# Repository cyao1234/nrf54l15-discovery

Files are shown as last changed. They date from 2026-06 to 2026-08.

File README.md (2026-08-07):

# nRF54L15 Discovery

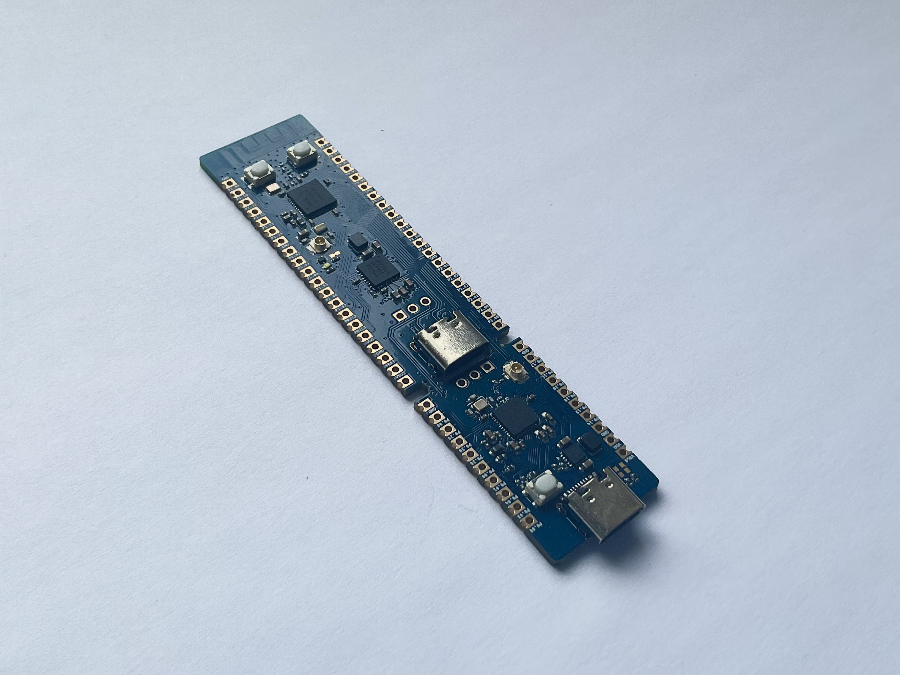
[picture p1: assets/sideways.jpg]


The nRF54L15 Discovery board is a development kit designed around the nRF54L15 and nRF52820 multiprotocol Bluetooth low-power SoCs. In the normal configuration, the nRF52820 is used as an interface CMSIS-DAP MCU, enabling onboard debugging and programming, eliminating the need for external debuggers. The Interface MCU interfaces with the host via USB and exposes an SWD and UART bridge for development usage.

Both MCUs are connected via two mousebite bridges, which can be snapped in two, allowing both chips to be used separately. Both boards have standalone voltage regulators and have their own USB-C power supply connector.

The processors are paired with an nPM1300 PMIC that supports LiPo charging and a TPS63900 high-efficiency, low Iq buck-boost converter. Both voltage regulators can be configured for 1.8V or 3.3V, enabling a flexible operating voltage domain. The nPM1300 also negotiates USB-C PD with your charger and dynamically changes the battery charging rate.

It also has USB-C, LEDs, Buttons, and U.FL receptacles for a 2.4 GHz Antenna and a 13.56 MHz NFC Antenna. The SWD and UART headers are exposed via I/O pins.

### Key Features
- Nordic Semiconductor [nRF54L15](https://www.nordicsemi.com/Products/nRF54L15) SoC
    - 128 MHz Arm Cortex®-M33 processor and 128 MHz RISC-V coprocessor 
    - 1.5 MB NVM and 256 KB RAM
    - Multiprotocol 2.4 GHz radio supporting Bluetooth Low Energy, 802.15.4-2020, and 2.4 GHz proprietary modes (up to 4 Mbps)
    - Advanced security features with physical protection
    - Global RTC (GRTC) available in System OFF mode
    - 5x SPI/UART/I2C, 3x PWM, 2x QDEC, I2S, PDM, 14-bit ADC, GPIOs
    - Integrated NFC-A Tag
    - 0.7 μA to 2.9 μA sleep mode power consumption
    - U.FL NFC connector
- Nordic Semiconductor [nRF52820](https://www.nordicsemi.com/Products/nRF52820) SoC
    - 64 MHz Arm Cortex®-M4
    - 256 KB Flash and 32 KB RAM
    - Full Speed USB 2.0
    - Bluetooth Low Energy multiprotocol
    - U.FL 2.4GHz NFC Antenna
- [nPM1300](https://www.nordicsemi.com/Products/nPM1300) 500 nA PMIC with integrated 32-800mA LiPo battery charger
    - 200 mA buck-boost converter with 93% efficiency
    - 50 mA switchable LDO for LEDs (turn off for 0 current leakage)
    - 1.0-3.3V variable voltage configurable in 100 mV steps
    - 32-800 mA LiPo battery charger with power path
    - USB Type-C compliant with 100 mA, 500 mA, and 1500 mA current limit
- Up to 48 GPIOs (29 for nRF54L15, 15 for nRF52820, 2 for nPM1300)
- Shipped with CMSIS-DAP pre-flashed on the nRF52820, ready for direct use
- ARM Serial Wire Debug (SWD) port via edge pins and 3-pin header
- TPS63900 75 nA buck-boost converter with 1.8V/3.3V configurable power supply for I/Os
- USB-C, user LED and buttons
- Dual-row 40+20 pins in 91x21mm form factor with castellated edges
- Snappable into 2 individual devboards, all capable of standalone operations
- Supports Zephyr, nRF Connect SDK, Python, etc.



### Hardware Diagram

The hardware design files are also available on [GitHub](https://github.com/cheyao/nrf54l15-discovery/), licensed under the CERN OHL V2.

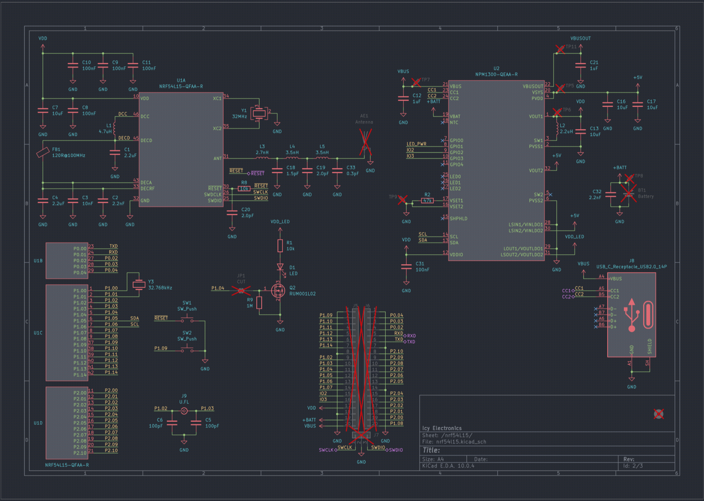
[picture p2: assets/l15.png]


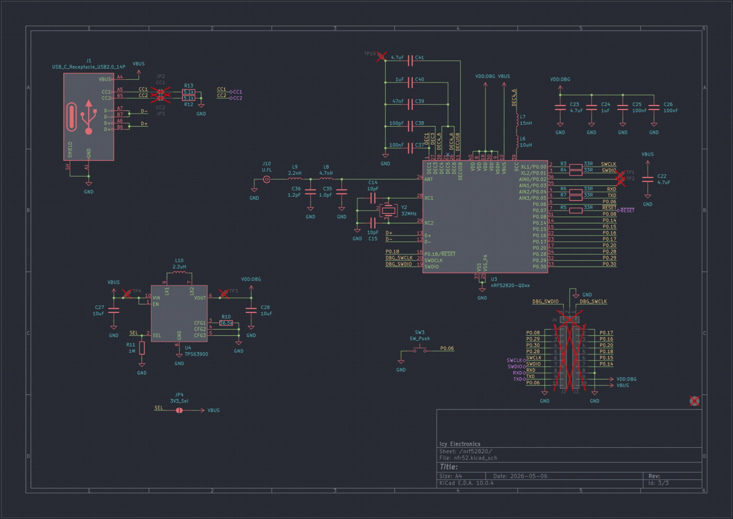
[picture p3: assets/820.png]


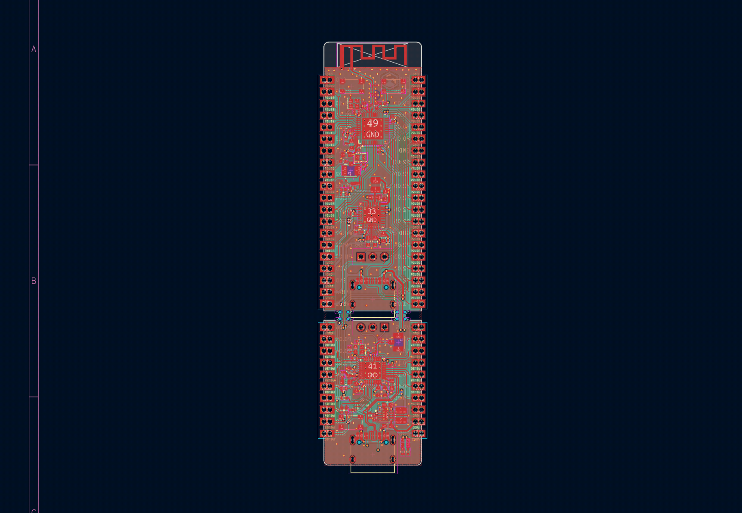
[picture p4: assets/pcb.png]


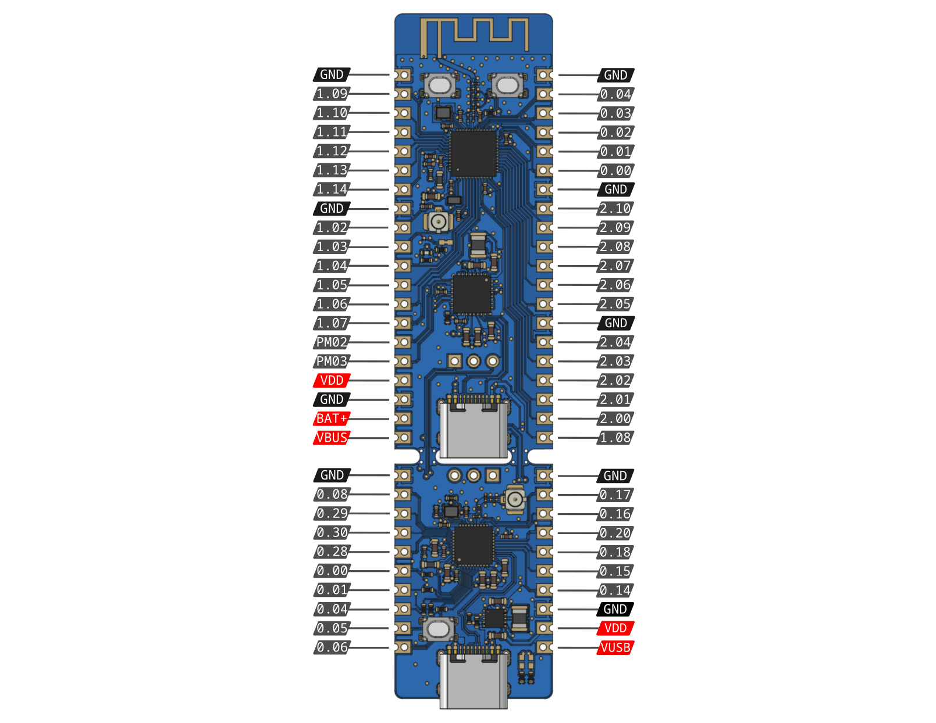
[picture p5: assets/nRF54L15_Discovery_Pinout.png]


### Programming guide

The board is programmable out of the box. Just run `west flash -r pyocd` to flash the board.

To get started, just follow Zephyr's [Getting Started](https://docs.zephyrproject.org/latest/develop/getting_started/index.html) guide. Everything is the same, except replace `<your-board-name>` with `nrf54l15_discovery/nrf54l15/cpuapp/s` (or without the `/ns` for secure version).

### Where to Buy

The nRF54L15 Discovery is available on the following sites:



(Got some extra units; cost covers material costs)

| Item | Price |
| --- | ---- |
| PCB | $120 |
| PCBA | $230 |

Download firmware here:
https://github.com/cheyao/nrf54l15-discovery/releases/tag/v1.0

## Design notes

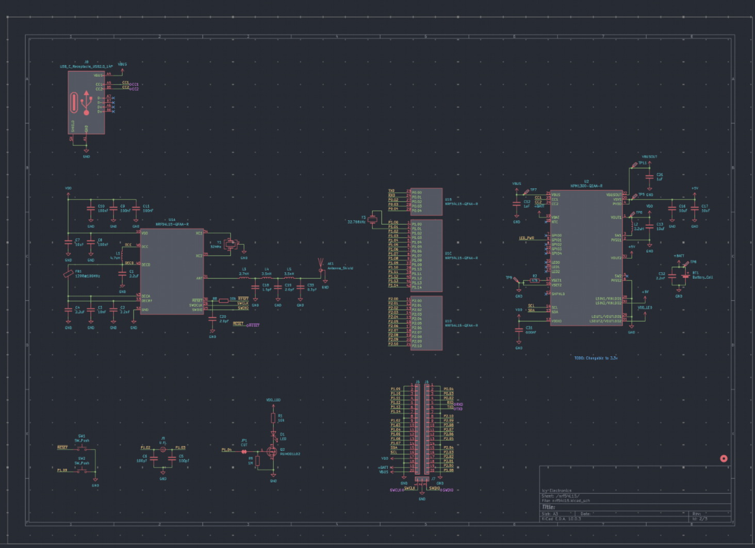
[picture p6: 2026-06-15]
assets/schematic-1.png

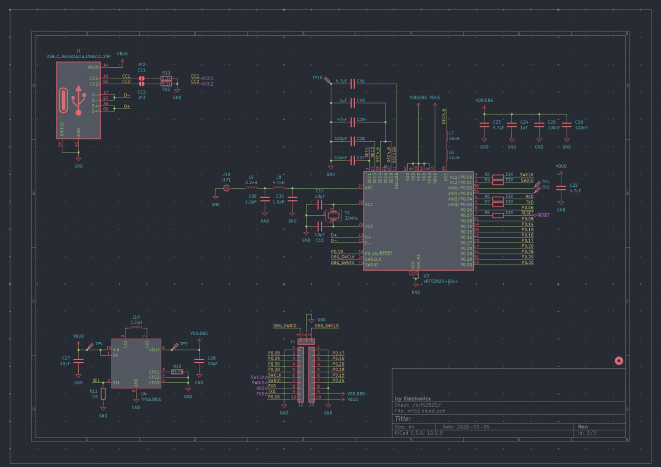
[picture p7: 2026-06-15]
assets/schematic-2.png

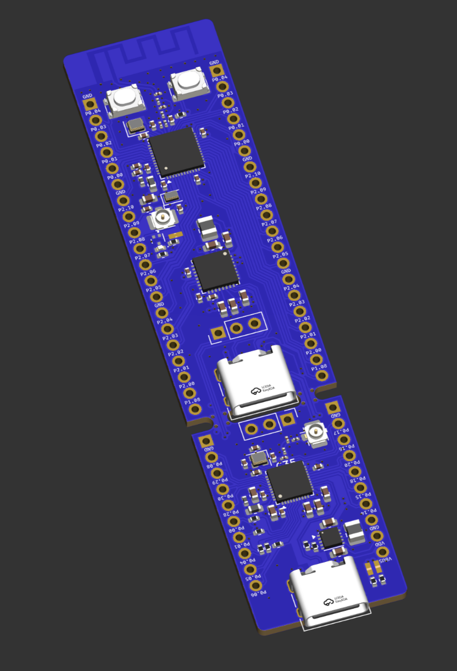
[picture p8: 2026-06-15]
assets/3d.png

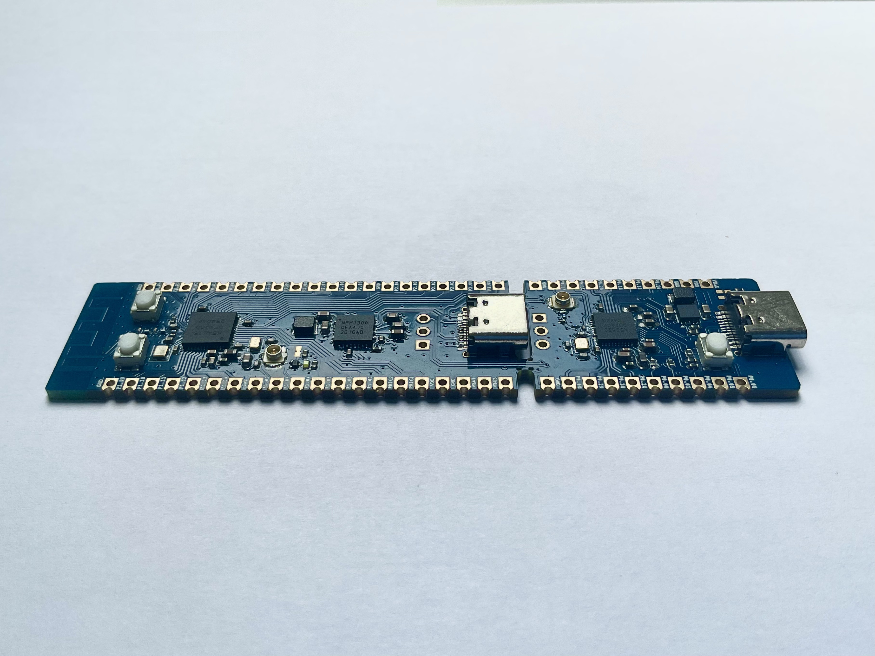
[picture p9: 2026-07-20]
assets/side.jpg

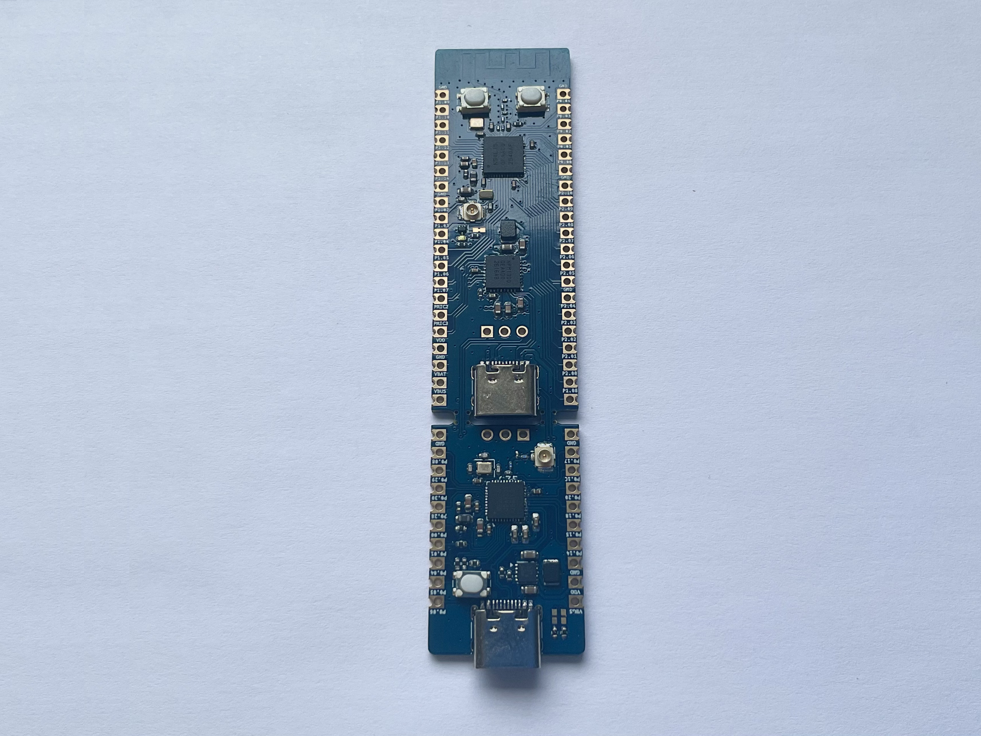
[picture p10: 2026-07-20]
assets/top-tilt.jpg

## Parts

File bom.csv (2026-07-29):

Item | Price
PCB | $120
PCBA | $230

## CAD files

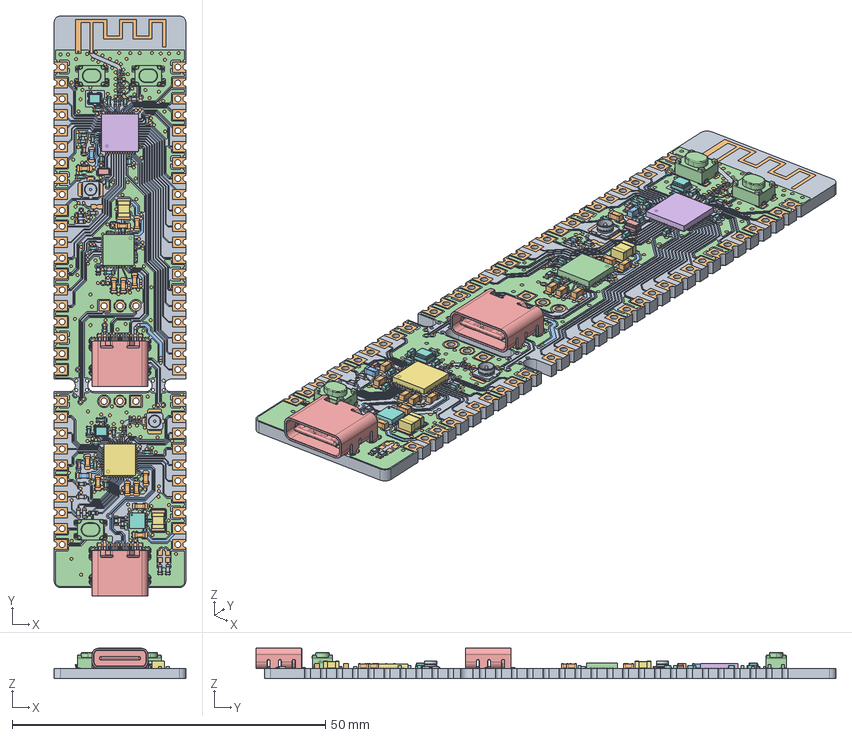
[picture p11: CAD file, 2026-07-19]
3d/nrf54.FCStd
21.0 x 92.5 x 4.87 mm
Pcb_dc15
topPads_dc15_cut
topTracks_dc15
topZones_dc15
botPads_dc15_cut
botTracks_dc15
botZones_dc15
C4_C_0402_1005Metric_efb7edfbfd87 x 20
R9_R_0402_1005Metric_148c62ffb333 x 13
L5_L_0201_0603Metric_c4573e2ac0c8 x 5
L1_L_0603_1608Metric_76ec2d2837d6 x 2
SW3_SW-SMD_4P-L4.2-W3.3-H2.5-P2.15-LS4.6_45902ee3bc6a x 3
USB-C_SMD-TYPE-C-31-M-12 x 2
U1_QFN_40_1EP_6x6mm_P05mm_bd9eb4529c85
L10_L_1008_2520Metric_1d597aab689b x 2
Y2_Crystal_SMD_2016-4Pin_2.0x1.6mm_cf03c7da0a9a x 2
J10_U.FL_Hirose_U.FL-R-SMT-1_Vertical_466a81a68c22 x 2
C21_C_0603_1608Metric_c42bb9afa9cc x 13
D1_LED_0402_1005Metric_9d2b405d5a38
U2_QFN_32_1EP_5x5mm_P05mm_EP33x33mm_112c5a95d446
FB1_L_0402_1005Metric_704f29023113 x 2
C36_C_0201_0603Metric_72dd63ce93f5 x 5
U3_QFN-40-1EP_5x5mm_Pitch0.4mm_b75e0b20a972
7a0a9878-926b-11ed-8620-a0cec80452fd_part
7a0a9b48-926b-11ed-8620-a0cec80452fd_part
7a0a9b48-926b-11ed-8620-a0cec80452fd_part001
7a0a9b48-926b-11ed-8620-a0cec80452fd_part002
7a0a9b48-926b-11ed-8620-a0cec80452fd_part003
7a0a9b48-926b-11ed-8620-a0cec80452fd_part004
7a0a9b48-926b-11ed-8620-a0cec80452fd_part005
7a0a9b48-926b-11ed-8620-a0cec80452fd_part006
7a0a9b48-926b-11ed-8620-a0cec80452fd_part007
7a0a9b48-926b-11ed-8620-a0cec80452fd_part008
7a0a9b48-926b-11ed-8620-a0cec80452fd_part009
7a0a9b48-926b-11ed-8620-a0cec80452fd_part010
7a0a9db4-926b-11ed-8620-a0cec80452fd_part

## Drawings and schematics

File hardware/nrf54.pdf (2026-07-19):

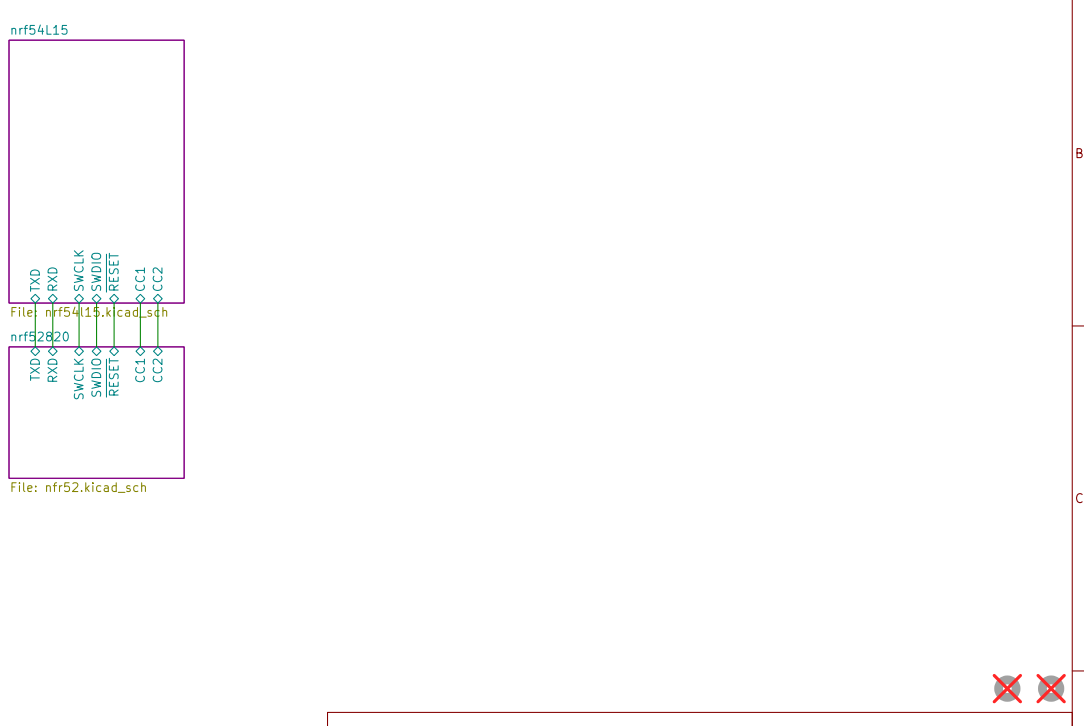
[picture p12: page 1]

Size: A4 | Rev: v1.0
KiCad E.D.A. 10.0.4 | Id: 1/3

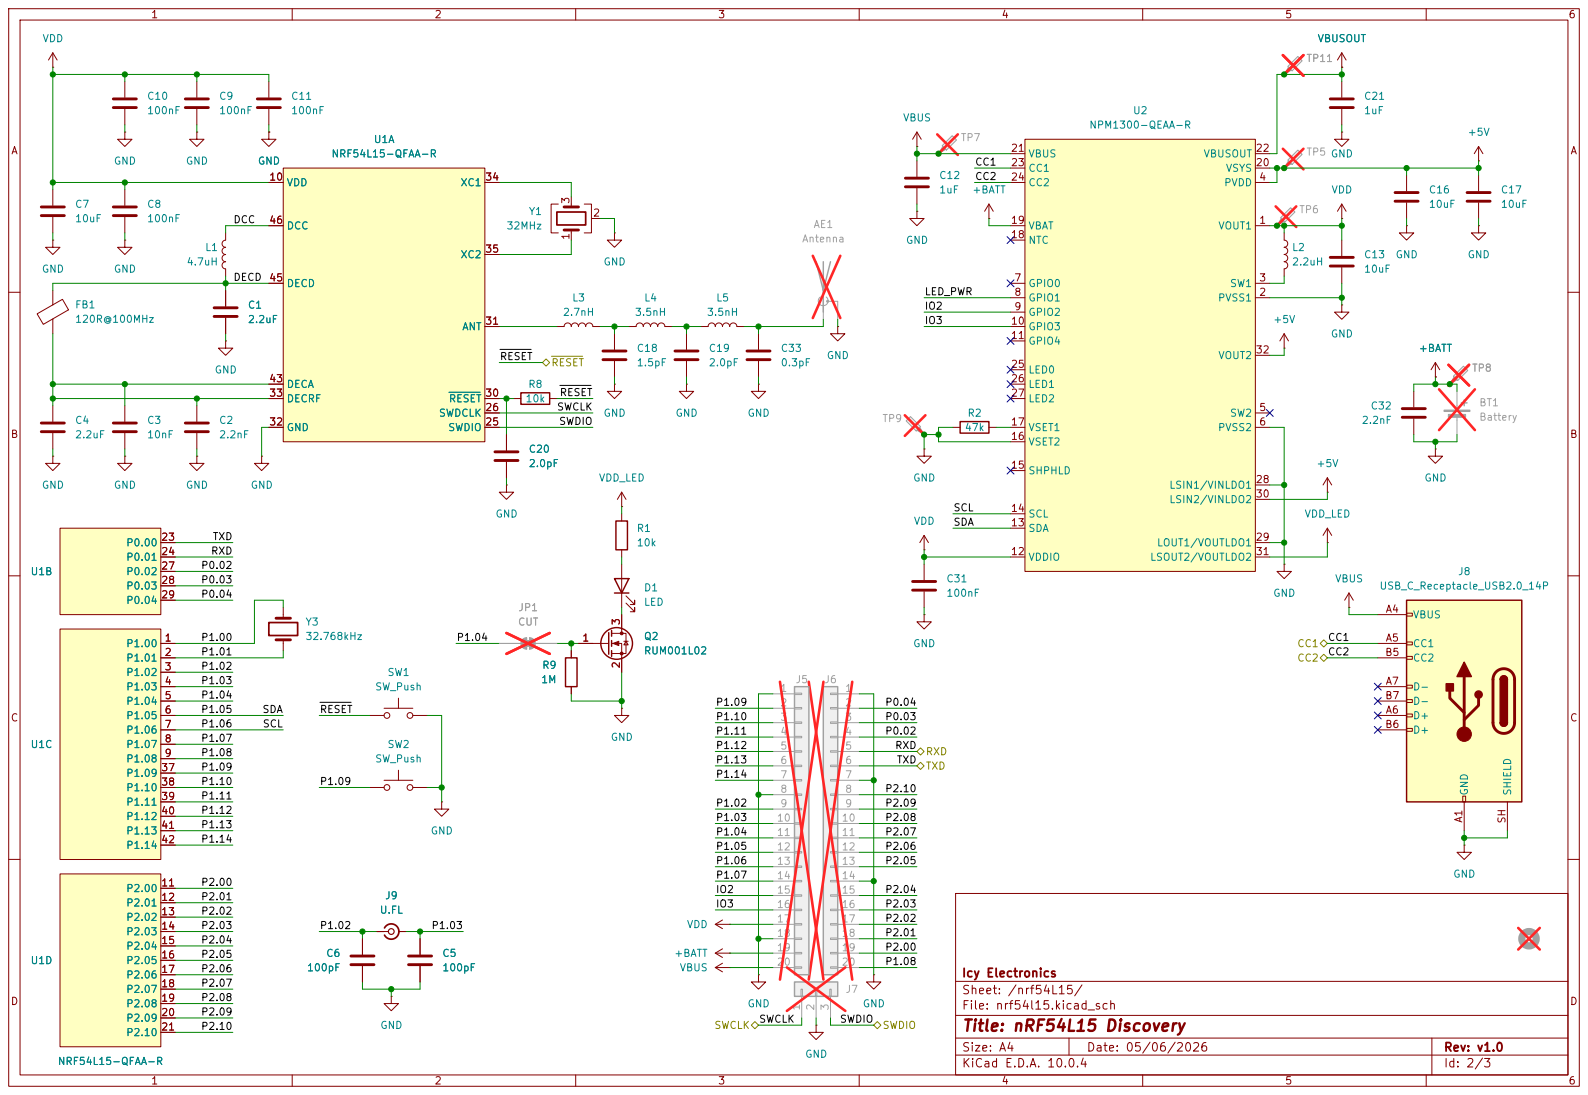
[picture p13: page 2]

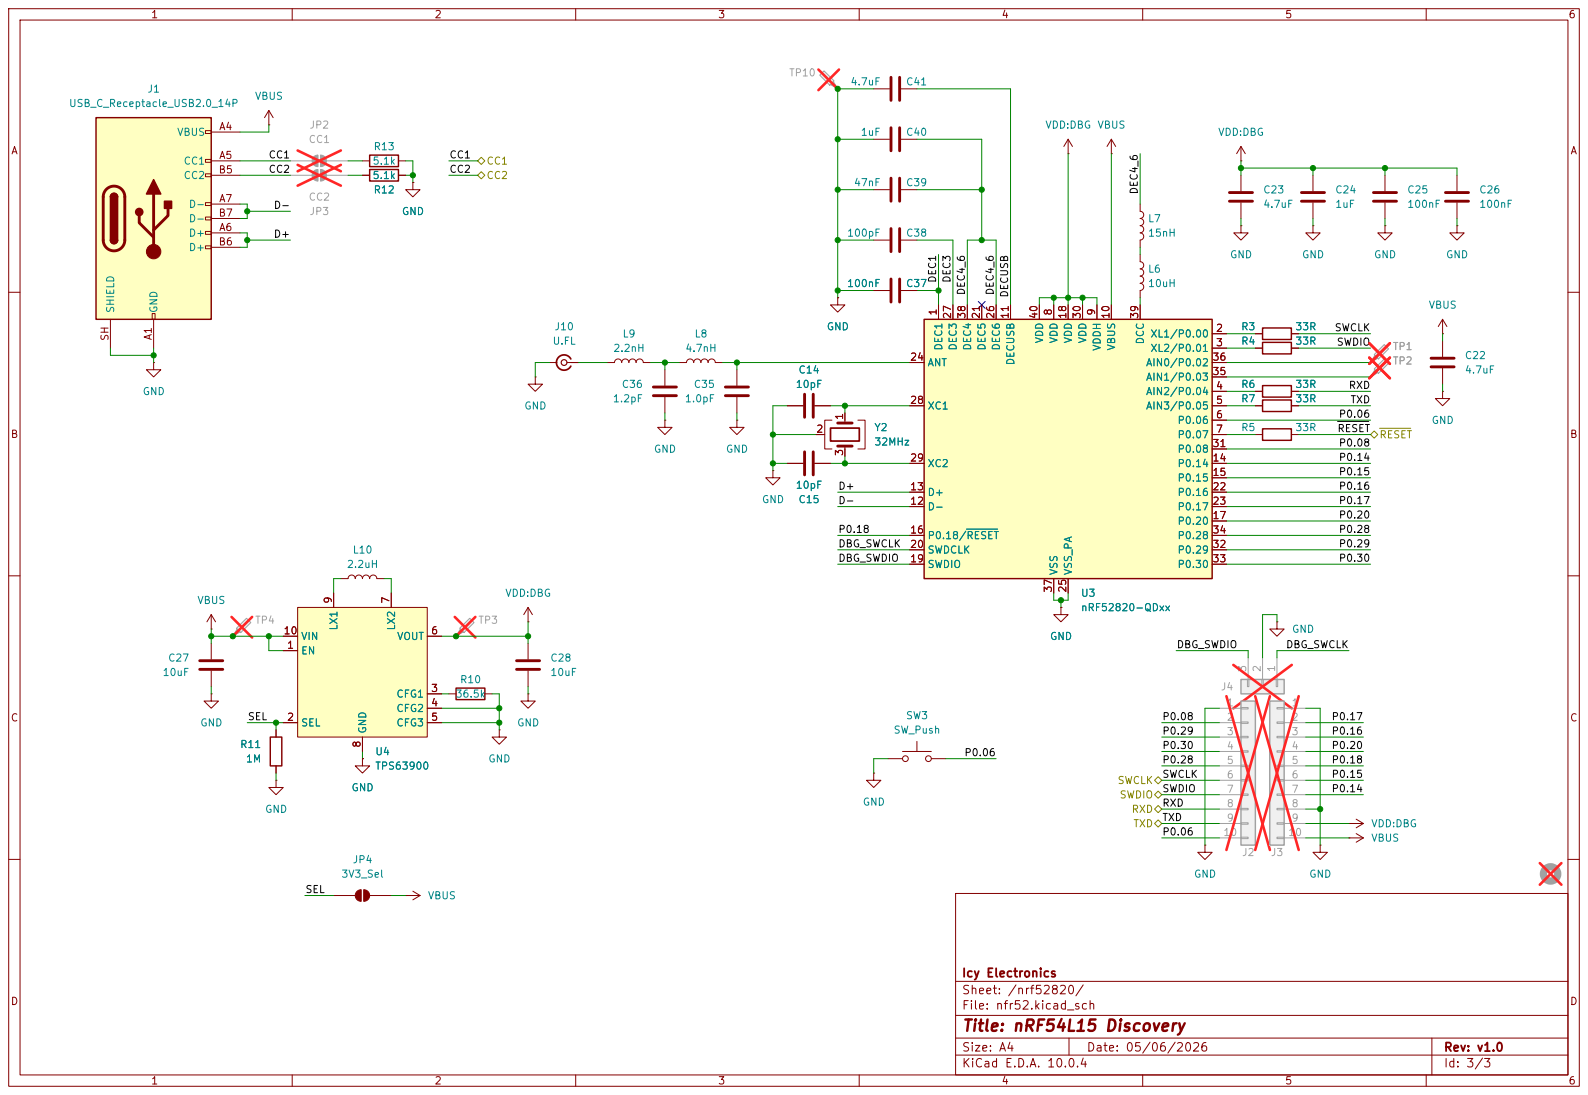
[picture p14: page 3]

9 VBUS 10 DECUSB 11 D- 12 D+ 13 P0.14 14 P0.15 15 P0.18/RESET 16 P0.20 17 VDD 18
nRF52820-QDxx DEC1

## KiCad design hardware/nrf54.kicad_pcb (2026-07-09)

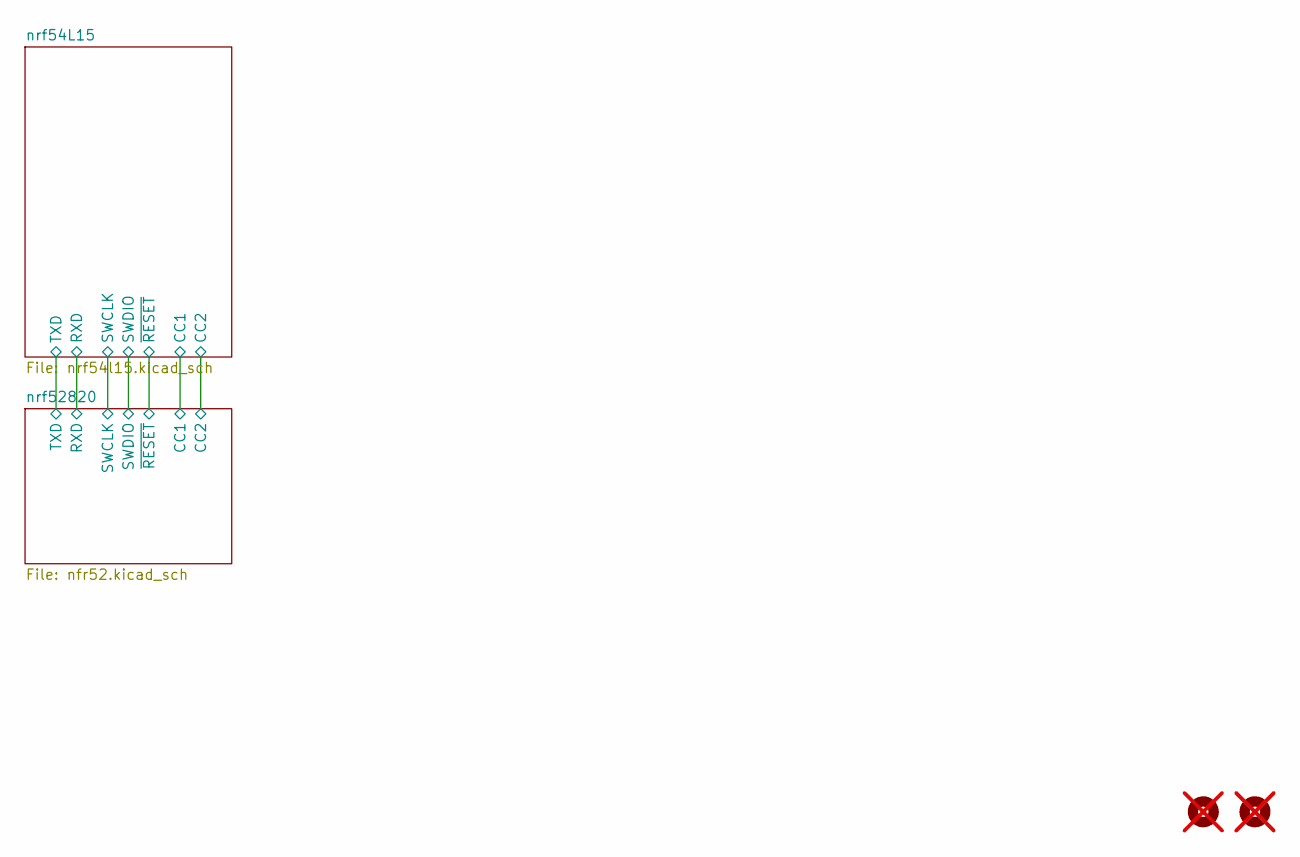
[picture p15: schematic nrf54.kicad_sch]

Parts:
H3, H4: MountingHole; MouseBite-Slot_2.0x2.0mm_outset_D0.5mm_P0.85mm_2h_Trace; not fitted

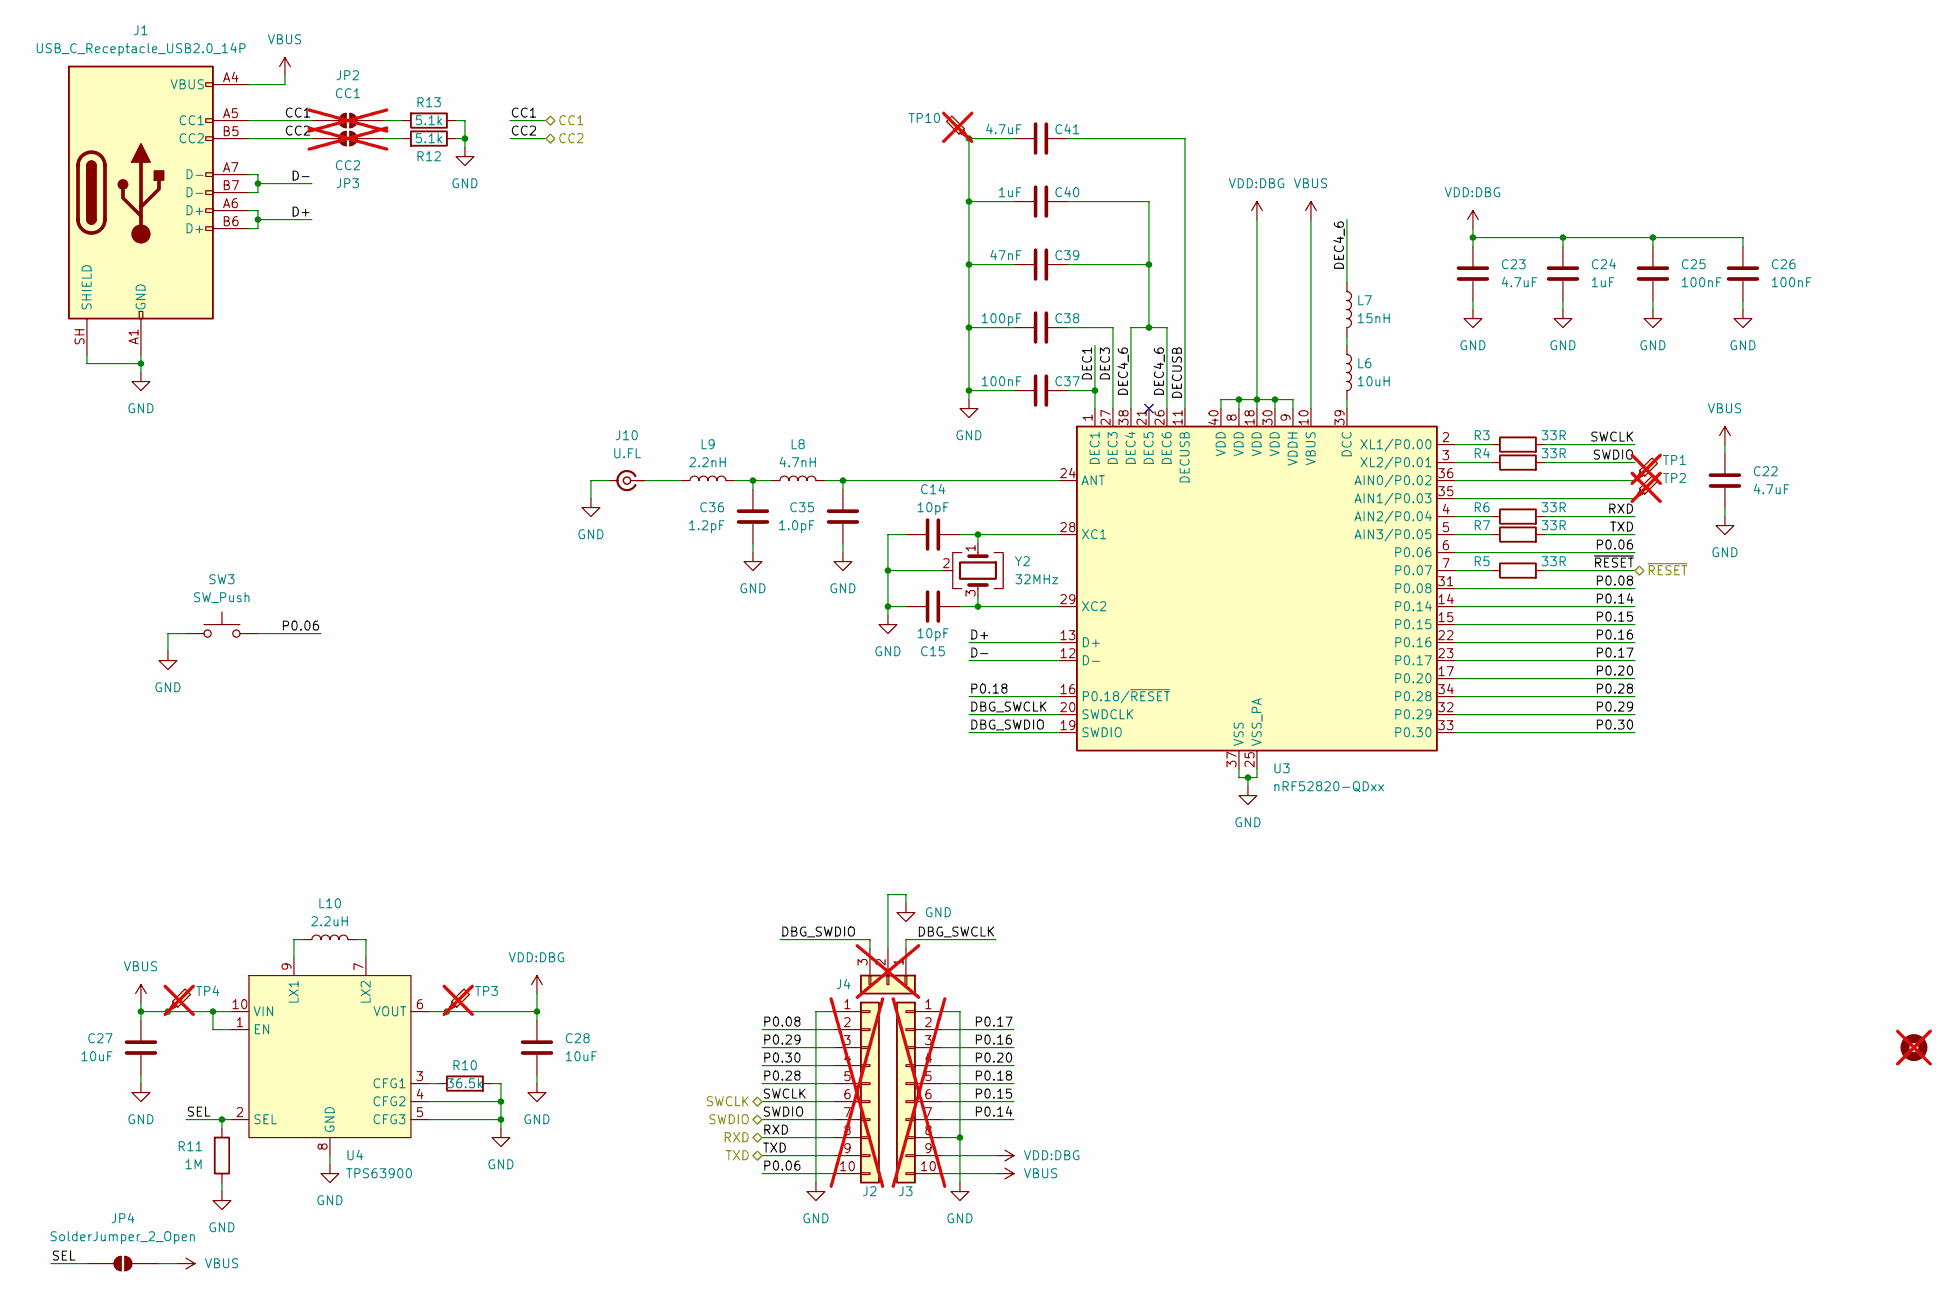
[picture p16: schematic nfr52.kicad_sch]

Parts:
C14, C15: 10pF; C_0402_1005Metric; LCSC Part # C106199
C22, C23, C41: 4.7uF; C_0603_1608Metric; LCSC Part # C380302
C24, C40: 1uF; C_0603_1608Metric; LCSC Part # C519560
C25, C26, C37: 100nF; C_0402_1005Metric; LCSC Part # C60474
C27, C28: 10uF; C_0603_1608Metric; LCSC Part # C7432767
C35: 1.0pF; C_0201_0603Metric; LCSC Part # C85893
C36: 1.2pF; C_0201_0603Metric; LCSC Part # C22374839
C38: 100pF; C_0402_1005Metric; LCSC Part # C541383
C39: 47nF; C_0402_1005Metric; LCSC Part # C272875
H1: MountingHole; Icy Electronics Logo; not fitted
J1: USB_C_Receptacle_USB2.0_14P; USB_C_Receptacle_HRO_TYPE-C-31-M-12; LCSC Part # C2681555
J2, J3: Conn_01x10; Castellated_1x10_P2.54mm_Vertical; not fitted
J4: Conn_01x03; PinHeader_1x03_P2.54mm_Vertical; not fitted
J10: U.FL; U.FL_Hirose_U.FL-R-SMT-1_Vertical; LCSC Part # C88374
JP2: CC1; SolderJumper-2_Open_Pad_Small; not fitted
JP3: CC2; SolderJumper-2_Open_Pad_Small; not fitted
JP4: SolderJumper_2_Open; SolderJumper-2_Open_Pad_Small
L6: 10uH; L_0603_1608Metric; LCSC Part # C281107
L7: 15nH; L_0402_1005Metric; LCSC Part # C86059
L8: 4.7nH; L_0201_0603Metric; LCSC Part # C86126
L9: 2.2nH; L_0201_0603Metric; LCSC Part # C98041
L10: 2.2uH; L_1008_2520Metric; LCSC Part # C5832372
R3, R4, R5, R6, R7: 33R; R_0402_1005Metric; LCSC Part # C2906931
R10: 36.5k; R_0402_1005Metric; LCSC Part # C49010116
R11: 1M; R_0402_1005Metric; LCSC Part # C2906900
R12, R13: 5.1k; R_0402_1005Metric; LCSC Part # C852856
SW3: SW_Push; SW_Push_SPST_TSA016; LCSC Part # C2888428
TP1, TP2, TP3, TP4, TP10: TestPoint_Probe; TestPoint_Pad_D1.0mm; not fitted
U3: nRF52820-QDxx; QFN-40-1EP_5x5mm_P0.4mm_EP3.6x3.6mm_ThermalVias
U4: TPS63900; WSON-10-1EP_2.5x2.5mm_P0.5mm_EP1.2x2mm_ThermalVias; LCSC Part # C1518762
Y2: 32MHz; Crystal_SMD_2016-4Pin_2.0x1.6mm; LCSC Part # C5339095

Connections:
/nrf52820/CC1: J1.A5 (CC1), JP2.1 (A); also elsewhere on the board
/nrf52820/CC2: J1.B5 (CC2), JP3.1 (A); also elsewhere on the board
/nrf52820/D+: J1.A6 (D+), J1.B6 (D+), U3.13 (D+)
/nrf52820/D-: J1.A7 (D-), J1.B7 (D-), U3.12 (D-)
/nrf52820/DBG_SWCLK: J4.1, U3.20 (SWDCLK)
/nrf52820/DBG_SWDIO: J4.3, U3.19 (SWDIO)
/nrf52820/DEC1: C37.2, U3.1 (DEC1)
/nrf52820/DEC3: C38.2, U3.27 (DEC3)
/nrf52820/DEC4_6: C39.2, C40.2, L7.1, U3.26 (DEC6), U3.38 (DEC4)
/nrf52820/DECUSB: C41.2, U3.11 (DECUSB)
/nrf52820/P0.06: J2.10, SW3.1, U3.6 (P0.06)
/nrf52820/P0.08: J2.2, U3.31 (P0.08)
/nrf52820/P0.14: J3.7, U3.14 (P0.14)
/nrf52820/P0.15: J3.6, U3.15 (P0.15)
/nrf52820/P0.16: J3.3, U3.22 (P0.16)
/nrf52820/P0.17: J3.2, U3.23 (P0.17)
/nrf52820/P0.18: J3.5, U3.16 (P0.18/~RESET)
/nrf52820/P0.20: J3.4, U3.17 (P0.20)
/nrf52820/P0.28: J2.5, U3.34 (P0.28)
/nrf52820/P0.29: J2.3, U3.32 (P0.29)
/nrf52820/P0.30: J2.4, U3.33 (P0.30)
/nrf52820/RXD: J2.8, R6.2; also elsewhere on the board
/nrf52820/SEL: JP4.1 (A), R11.2, U4.2 (SEL)
/nrf52820/SWCLK: J2.6, R3.2; also elsewhere on the board
/nrf52820/SWDIO: J2.7, R4.2; also elsewhere on the board
/nrf52820/TXD: J2.9, R7.2; also elsewhere on the board
/nrf52820/~RESET: R5.2; also elsewhere on the board
GND: C14.1, C15.1, C22.2, C23.2, C24.2, C25.2, C26.2, C27.2, C28.2, C35.2, C36.2, C37.1, C38.1, C39.1, C40.1, C41.1, J1.A1 (GND), J1.A12 (GND), J1.B1 (GND), J1.B12 (GND), J1.SH (SHIELD), J2.1, J3.1, J3.8, J4.2, J10.2 (Ext), R10.2, R11.1, R12.1, R13.1, SW3.2, TP10.1 (1_1), U3.25 (VSS_PA), U3.37 (VSS), U3.41 (VSS), U4.4 (CFG2), U4.5 (CFG3), U4.8 (GND), U4.11 (GND), Y2.2 (G), Y2.4 (G); also elsewhere on the board
unnamed: C36.1, L8.1, L9.2
unnamed: J10.1 (In), L9.1
unnamed: JP2.2 (B), R13.2
unnamed: JP3.2 (B), R12.2
unnamed: L6.1, L7.2
unnamed: TP1.1 (1_1), U3.36 (AIN0/P0.02)
unnamed: TP2.1 (1_1), U3.35 (AIN1/P0.03)
unnamed: R6.1, U3.4 (AIN2/P0.04)
unnamed: R7.1, U3.5 (AIN3/P0.05)
unnamed: C35.1, L8.2, U3.24 (ANT)
unnamed: L6.2, U3.39 (DCC)
unnamed: R5.1, U3.7 (P0.07)
unnamed: C14.2, U3.28 (XC1), Y2.1
unnamed: C15.2, U3.29 (XC2), Y2.3
unnamed: R3.1, U3.2 (XL1/P0.00)
unnamed: R4.1, U3.3 (XL2/P0.01)
unnamed: R10.1, U4.3 (CFG1)
unnamed: L10.1, U4.9 (LX1)
unnamed: L10.2, U4.7 (LX2)
VBUS: C22.1, C27.1, J1.A4 (VBUS), J1.A9 (VBUS), J1.B4 (VBUS), J1.B9 (VBUS), J3.10, JP4.2 (B), TP4.1 (1_1), U3.10 (VBUS), U4.1 (EN), U4.10 (VIN); also elsewhere on the board
VDD:DBG: C23.1, C24.1, C25.1, C26.1, C28.1, J3.9, TP3.1 (1_1), U3.8 (VDD), U3.9 (VDDH), U3.18 (VDD), U3.30 (VDD), U3.40 (VDD), U4.6 (VOUT)

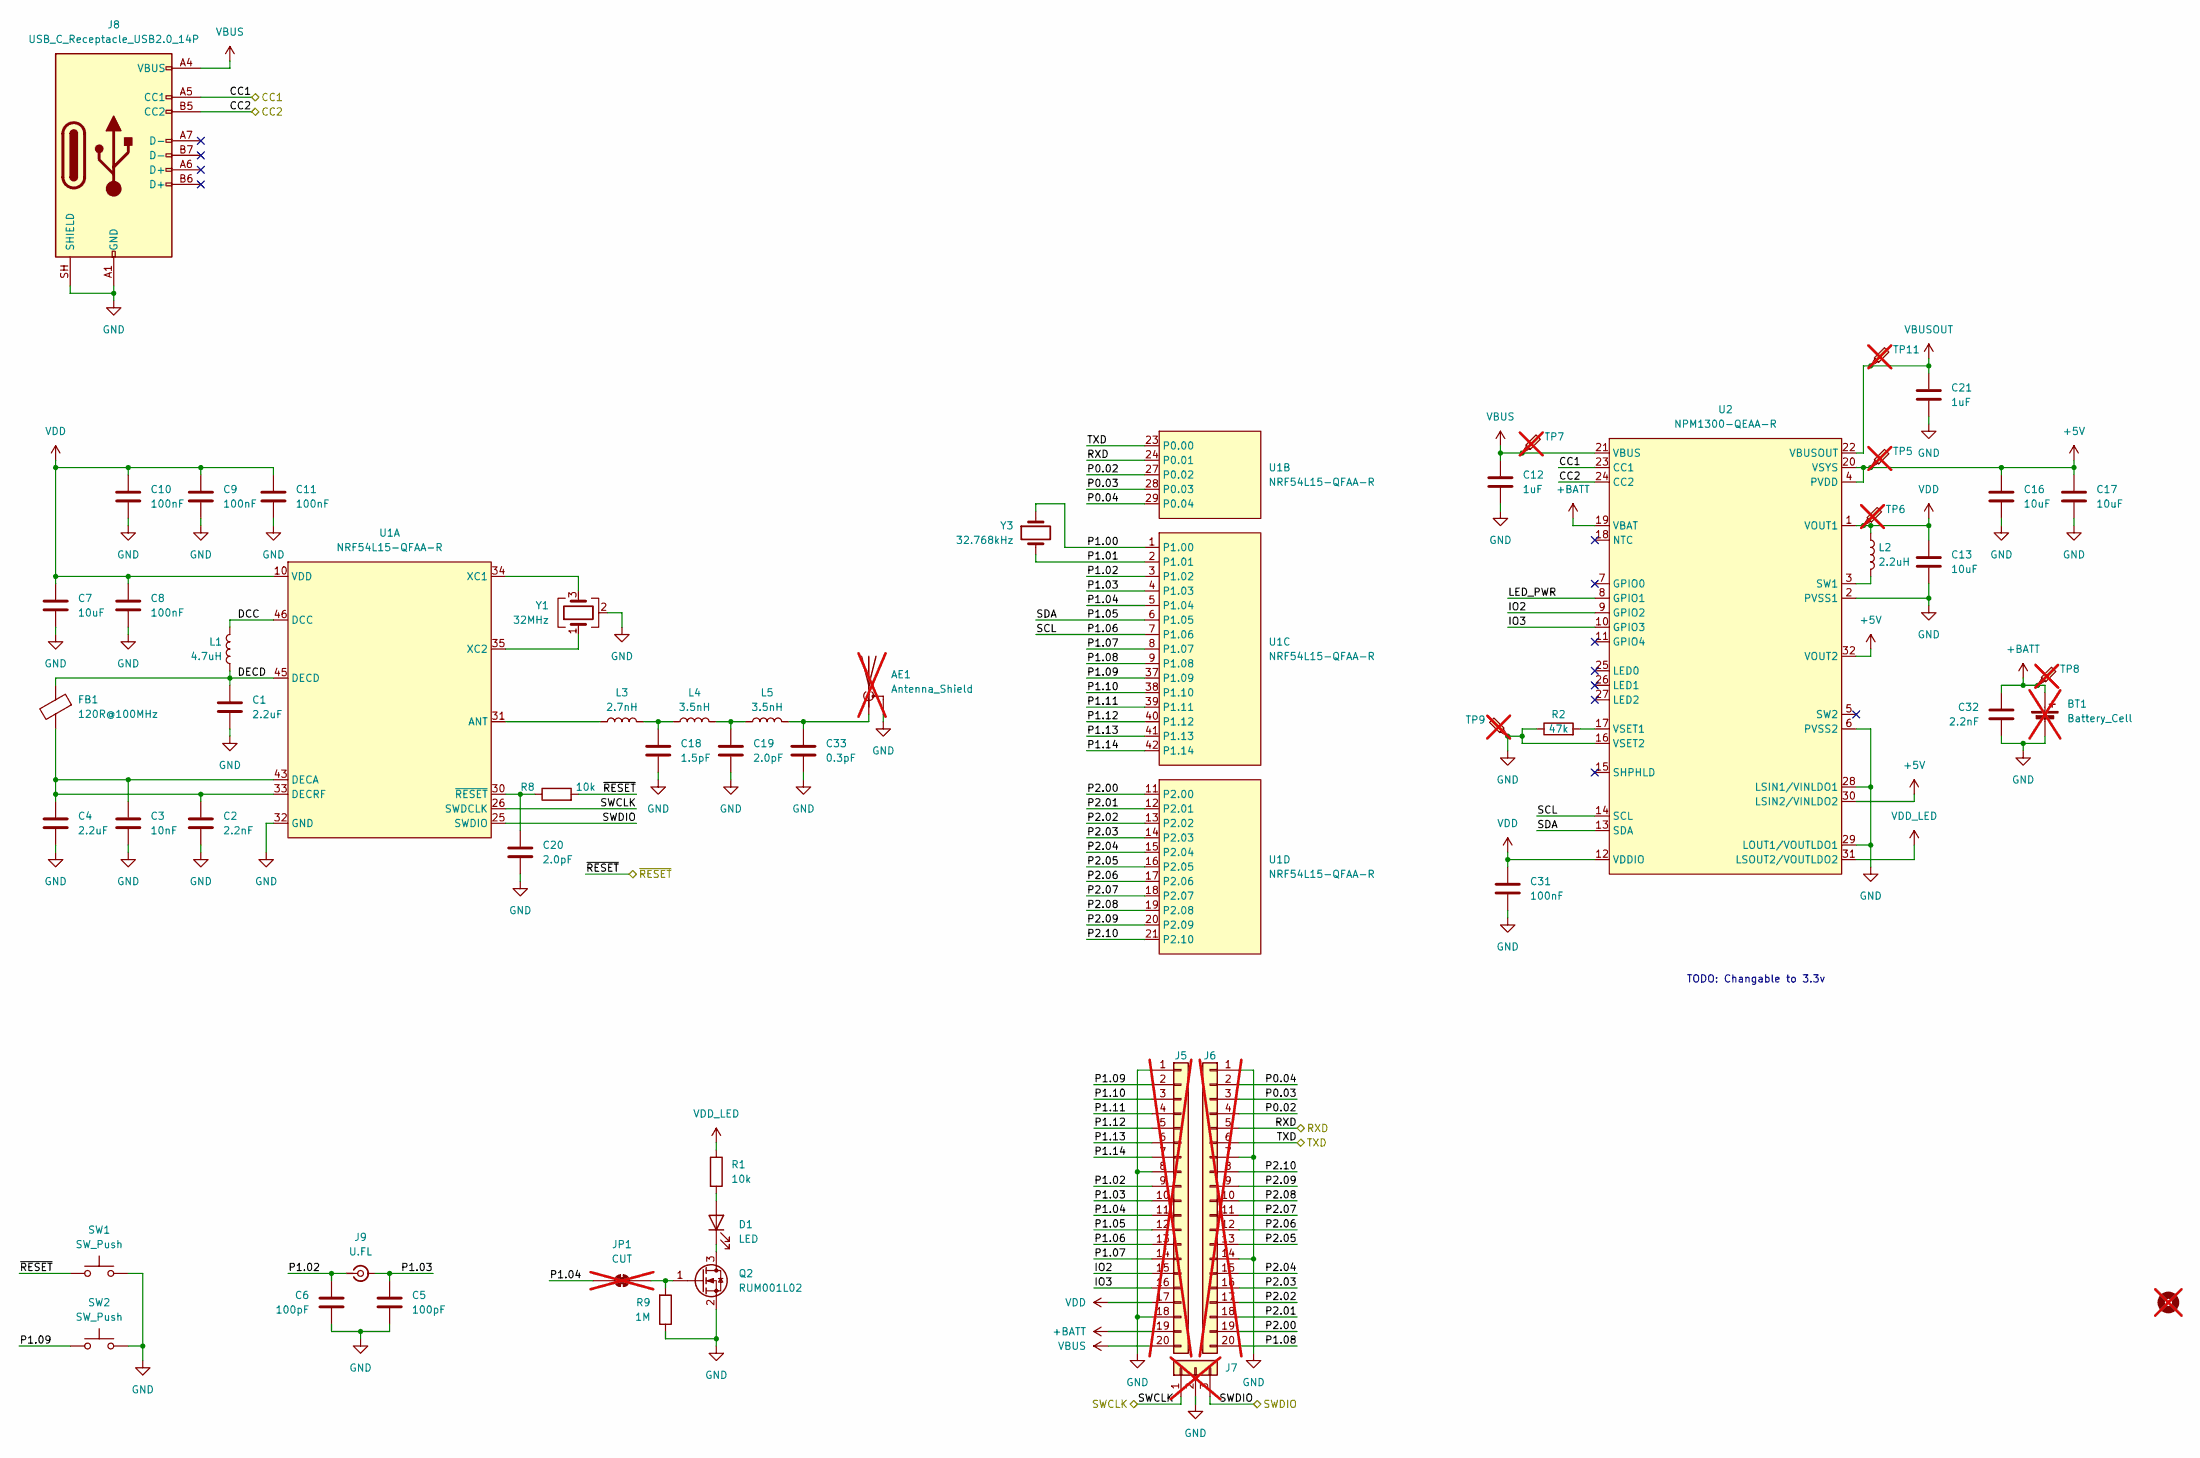
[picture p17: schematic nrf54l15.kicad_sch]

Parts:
AE1: Antenna_Shield; Texas_SWRA117D_2.4GHz_Right; not fitted
BT1: Battery_Cell; not fitted
C1, C4: 2.2uF; C_0402_1005Metric; LCSC Part # C723363
C2, C32: 2.2nF; C_0402_1005Metric; LCSC Part # C106861
C3: 10nF; C_0402_1005Metric; LCSC Part # C5137480
C5, C6: 100pF; C_0402_1005Metric; LCSC Part # C541383
C7, C13, C16, C17: 10uF; C_0603_1608Metric; LCSC Part # C7432767
C8, C9, C10, C11, C31: 100nF; C_0402_1005Metric; LCSC Part # C60474
C12, C21: 1uF; C_0603_1608Metric; LCSC Part # C519560
C18: 1.5pF; C_0201_0603Metric; LCSC Part # C435397
C19: 2.0pF; C_0201_0603Metric; LCSC Part # C22374842
C20: 2.0pF; C_0402_1005Metric; LCSC Part # C281756
C33: 0.3pF; C_0201_0603Metric; LCSC Part # C723329
D1: LED; LED_0402_1005Metric; LCSC Part # C51933306
FB1: 120R@100MHz; L_0402_1005Metric; LCSC Part # C141722
H2: MountingHole; Icy Electronics Logo; not fitted
J5, J6: Conn_01x20; Castellated_1x20_P2.54mm_Vertical; not fitted
J7: Conn_01x03; PinHeader_1x03_P2.54mm_Vertical; not fitted
J8: USB_C_Receptacle_USB2.0_14P; USB_C_Receptacle_HRO_TYPE-C-31-M-12; LCSC Part # C2681555
J9: U.FL; U.FL_Hirose_U.FL-R-SMT-1_Vertical; LCSC Part # C88374
JP1: CUT; SolderJumper-2_Bridged_Pad_Small; not fitted
L1: 4.7uH; L_0603_1608Metric; LCSC Part # C394952
L2: 2.2uH; L_1008_2520Metric; LCSC Part # C5832372
L3: 2.7nH; L_0201_0603Metric; LCSC Part # C337946
L4, L5: 3.5nH; L_0201_0603Metric; LCSC Part # C3911055
Q2: RUM001L02; SOT-723; LCSC Part # C42412321
R1, R8: 10k; R_0402_1005Metric; LCSC Part # C2906861
R2: 47k; R_0402_1005Metric; LCSC Part # C163830
R9: 1M; R_0402_1005Metric; LCSC Part # C2906900
SW1, SW2: SW_Push; SW_Push_SPST_TSA016; LCSC Part # C2888428
TP5, TP6, TP7, TP8, TP9, TP11: TestPoint_Probe; TestPoint_Pad_D1.0mm; not fitted
U1: NRF54L15-QFAA-R; QFN-48-1EP_6x6mm_P0.4mm_EP4.6x4.6mm_ThermalVias
U2: NPM1300-QEAA-R; VQFN-32-1EP_5x5mm_P0.5mm_EP3.5x3.5mm_ThermalVias
Y1: 32MHz; Crystal_SMD_2016-4Pin_2.0x1.6mm; LCSC Part # C5339095
Y3: 32.768kHz; Crystal_SMD_2012-2Pin_2.0x1.2mm; LCSC Part # C99009

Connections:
+5V: C16.1, C17.1, TP5.1 (1_1), U2.4 (PVDD), U2.20 (VSYS), U2.30 (LSIN2/VINLDO2), U2.32 (VOUT2)
+BATT: BT1.1 (+), C32.1, J5.19, TP8.1 (1_1), U2.19 (VBAT)
/nrf54L15/DCC: L1.2, U1.46 (DCC)
/nrf54L15/DECD: C1.1, FB1.1, L1.1, U1.45 (DECD)
/nrf54L15/IO2: J5.15, U2.9 (GPIO2)
/nrf54L15/IO3: J5.16, U2.10 (GPIO3)
/nrf54L15/LED_PWR: U2.8 (GPIO1)
/nrf54L15/P0.02: J6.4, U1.27 (P0.02)
/nrf54L15/P0.03: J6.3, U1.28 (P0.03)
/nrf54L15/P0.04: J6.2, U1.29 (P0.04)
/nrf54L15/P1.00: U1.1 (P1.00), Y3.1
/nrf54L15/P1.01: U1.2 (P1.01), Y3.2
/nrf54L15/P1.02: C6.1, J5.9, J9.1 (In), U1.3 (P1.02)
/nrf54L15/P1.03: C5.1, J5.10, J9.2 (Ext), U1.4 (P1.03)
/nrf54L15/P1.04: J5.11, JP1.1 (A), U1.5 (P1.04)
/nrf54L15/P1.05: J5.12, U1.6 (P1.05), U2.13 (SDA)
/nrf54L15/P1.06: J5.13, U1.7 (P1.06), U2.14 (SCL)
/nrf54L15/P1.07: J5.14, U1.8 (P1.07)
/nrf54L15/P1.08: J6.20, U1.9 (P1.08)
/nrf54L15/P1.09: J5.2, SW2.1, U1.37 (P1.09)
/nrf54L15/P1.10: J5.3, U1.38 (P1.10)
/nrf54L15/P1.11: J5.4, U1.39 (P1.11)
/nrf54L15/P1.12: J5.5, U1.40 (P1.12)
/nrf54L15/P1.13: J5.6, U1.41 (P1.13)
/nrf54L15/P1.14: J5.7, U1.42 (P1.14)
/nrf54L15/P2.00: J6.19, U1.11 (P2.00)
/nrf54L15/P2.01: J6.18, U1.12 (P2.01)
/nrf54L15/P2.02: J6.17, U1.13 (P2.02)
/nrf54L15/P2.03: J6.16, U1.14 (P2.03)
/nrf54L15/P2.04: J6.15, U1.15 (P2.04)
/nrf54L15/P2.05: J6.13, U1.16 (P2.05)
/nrf54L15/P2.06: J6.12, U1.17 (P2.06)
/nrf54L15/P2.07: J6.11, U1.18 (P2.07)
/nrf54L15/P2.08: J6.10, U1.19 (P2.08)
/nrf54L15/P2.09: J6.9, U1.20 (P2.09)
/nrf54L15/P2.10: J6.8, U1.21 (P2.10)
/nrf52820/CC1: J8.A5 (CC1), U2.23 (CC1); also elsewhere on the board
/nrf52820/CC2: J8.B5 (CC2), U2.24 (CC2); also elsewhere on the board
/nrf52820/RXD: J6.5, U1.24 (P0.01); also elsewhere on the board
/nrf52820/SWCLK: J7.1, U1.26 (SWDCLK); also elsewhere on the board
/nrf52820/SWDIO: J7.3, U1.25 (SWDIO); also elsewhere on the board
/nrf52820/TXD: J6.6, U1.23 (P0.00); also elsewhere on the board
/nrf52820/~RESET: R8.2, SW1.1; also elsewhere on the board
GND: AE1.2 (Shield), BT1.2 (-), C1.2, C2.2, C3.2, C4.2, C5.2, C6.2, C7.2, C8.2, C9.2, C10.2, C11.2, C12.2, C13.2, C16.2, C17.2, C18.2, C19.2, C20.2, C21.2, C31.2, C32.2, C33.2, J5.1, J5.8, J5.18, J6.1, J6.7, J6.14, J7.2, J8.A1 (GND), J8.A12 (GND), J8.B1 (GND), J8.B12 (GND), J8.SH (SHIELD), Q2.2 (S), R2.1, R9.1, SW1.2, SW2.2, TP9.1 (1_1), U1.32 (GND), U1.44 (GND), U1.49 (GND), U2.2 (PVSS1), U2.6 (PVSS2), U2.16 (VSET2), U2.28 (LSIN1/VINLDO1), U2.29 (LOUT1/VOUTLDO1), U2.33 (GND), Y1.2 (G), Y1.4 (G); also elsewhere on the board
unnamed: AE1.1 (A), C33.1, L5.2
unnamed: C18.1, L3.2, L4.1
unnamed: C19.1, L4.2, L5.1
unnamed: D1.2 (A), R1.2
unnamed: D1.1 (K), Q2.3 (D)
unnamed: JP1.2 (B), Q2.1 (G), R9.2
unnamed: L3.1, U1.31 (ANT)
unnamed: C2.1, C3.1, C4.1, FB1.2, U1.33 (DECRF), U1.43 (DECA)
unnamed: U1.34 (XC1), Y1.3
unnamed: U1.35 (XC2), Y1.1
unnamed: C20.1, R8.1, U1.30 (~RESET)
unnamed: L2.2, U2.3 (SW1)
unnamed: R2.2, U2.17 (VSET1)
VBUS: C12.1, J5.20, J8.A4 (VBUS), J8.A9 (VBUS), J8.B4 (VBUS), J8.B9 (VBUS), TP7.1 (1_1), U2.21 (VBUS); also elsewhere on the board
VBUSOUT: C21.1, TP11.1 (1_1), U2.22 (VBUSOUT)
VDD: C7.1, C8.1, C9.1, C10.1, C11.1, C13.1, C31.1, J5.17, L2.1, TP6.1 (1_1), U1.10 (VDD), U1.22 (VDD), U1.36 (VDD), U1.47 (VDD), U1.48 (VDD), U2.1 (VOUT1), U2.12 (VDDIO)
VDD_LED: R1.1, U2.31 (LSOUT2/VOUTLDO2)

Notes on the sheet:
TODO: Changable to 3.3v

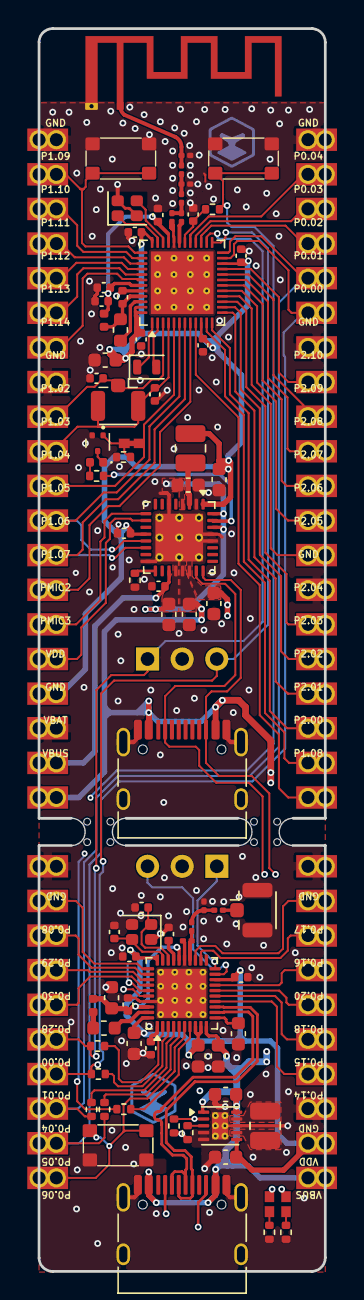
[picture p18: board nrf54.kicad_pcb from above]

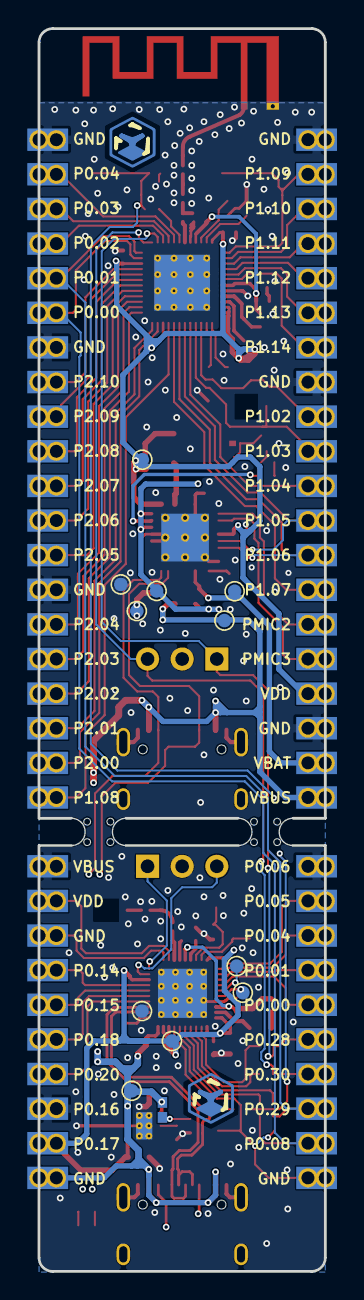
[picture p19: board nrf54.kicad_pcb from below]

Board: 4 copper layers, 21.0 x 91.2 mm, 104 parts (18 on the bottom side), 100 nets.

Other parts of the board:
H2#2: MountingHole; Icy Electronics Logo

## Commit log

2026-07-19 Add schematic
    [nfr52.kicad_sch, nrf54.FCStd, nrf54.kicad_sch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]
2026-07-20 Draw new assets and update readme
    [BOM.csv]
